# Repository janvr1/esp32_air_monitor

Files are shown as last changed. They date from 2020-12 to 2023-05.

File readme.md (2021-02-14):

### TO-DO:
* (SW) Ubidots

### Notes:
* GPIO 6-11: SPI flash
* GPIO 16-17: PSRAM
* GPIO 34-39: Input only
* EWMA filter: alpha = 2\*pi\*fc\*Ts/(1+2\*pi\*fc\*Ts)

### Display timings:
* F_pwm = 312,5 kHz (T=3,2 us)
* PWM: T_low@100%duty=~20 ns
* T_transfer = ~22 us (2 rows of 64 pixels * 3 colors)
* T_row = 200 us (T_transfer + 178 delay)
* Minimum brightness: T_on = 22 us (transfer time), T_off = 178 us (178 us delay)
* Maximum brightness: T_on = 200 us (22 us transfer + 178 us delay), T_off = 0 us
* Frame rate: 200..250 Hz (daylight), 100 Hz (nighttime)

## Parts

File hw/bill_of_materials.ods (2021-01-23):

Reference | Product | Type | Quantity | Price | Link
U1 | Microcontroller | Espressif DevKitC v4 | 1 | 10,00 € | Mouser (https://eu.mouser.com/ProductDetail/356-ESP32-DEVKITC32E/)
U2 | CO2 sensor | Sensirion SCD30 | 1 | 55,00 € | Mouser (https://eu.mouser.com/ProductDetail/403-SCD30/)
(J5) | T,RH sensor | Bosch BME280 | 1 | 15,00 € | Mouser (https://eu.mouser.com/ProductDetail/397-PIM472/)
(J4) | Light sensor | Vishay VEML7700 | 1 | 5,00 € | Mouser (https://eu.mouser.com/ProductDetail/485-4162/)
J2, J3 | Display connector | 2x8 Pin socket | 2
 | Display | 64x32 P3 Led matrix | 1 | 25,00 € | Ebay (https://www.ebay.com/itm/Panneau-de-pixels-LED-Matrix-P3-RVB-affichage-vidéo-HD-64x32-Module-décran-LED/273803679685)
J4 | Sensor connector | 1x5 Pin socket | 2
 | Sensor connector | 1x5 Pin header | 1
 | Sensor connector | 1x5 Pin header (right angle) | 1
J6 | Sensor connector | 1x7 Pin socket | 1
 | Sensor connector | 1x7 Pin header | 1
J1 | Power connector | 1x2 Pin header | 1
J1 | Power connector | 1x2 Pin socket | 1
 | Resistor | 10k SMD3216 | 7
 | DIP switch | x4 W7.62mm P2.54mm | 1
 | Button |  | 3

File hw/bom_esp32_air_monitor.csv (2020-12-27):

Id | Designator | Package | Quantity | Designation | Supplier and ref
1 | U1 | MODULE_ESP32-DEVKITC-32D | 1 | ESP32-DEVKITC-32D
2 | U2 | MODULE_SCD30 | 1 | SCD30
3 | J2,J3 | Connector_LED_matrix_64x32 | 2 | Connector_LED_matrix_64x32
4 | J5 | Connector_Adafruit_VEML7700 | 1 | Connector_Adafruit_VEML7700
5 | J4 | Connector_Pimoroni_BME280 | 1 | Connector_Pimoroni_BME280
6 | J1 | PinHeader_1x02_P2.54mm_Vertical | 1 | Conn_01x02_Male

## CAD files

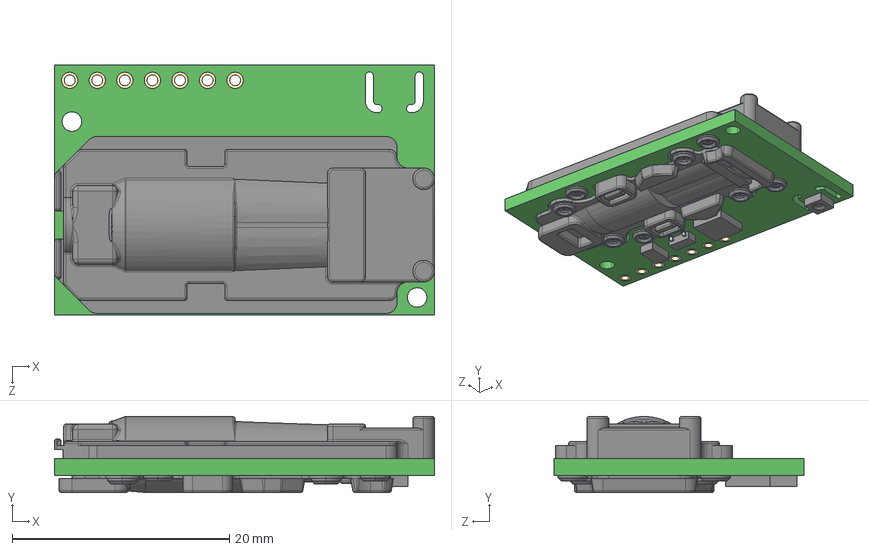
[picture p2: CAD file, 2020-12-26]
hw/libraries_footprints/kicad_SCD30/SCD30.step
35.0 x 7.00 x 23.0 mm

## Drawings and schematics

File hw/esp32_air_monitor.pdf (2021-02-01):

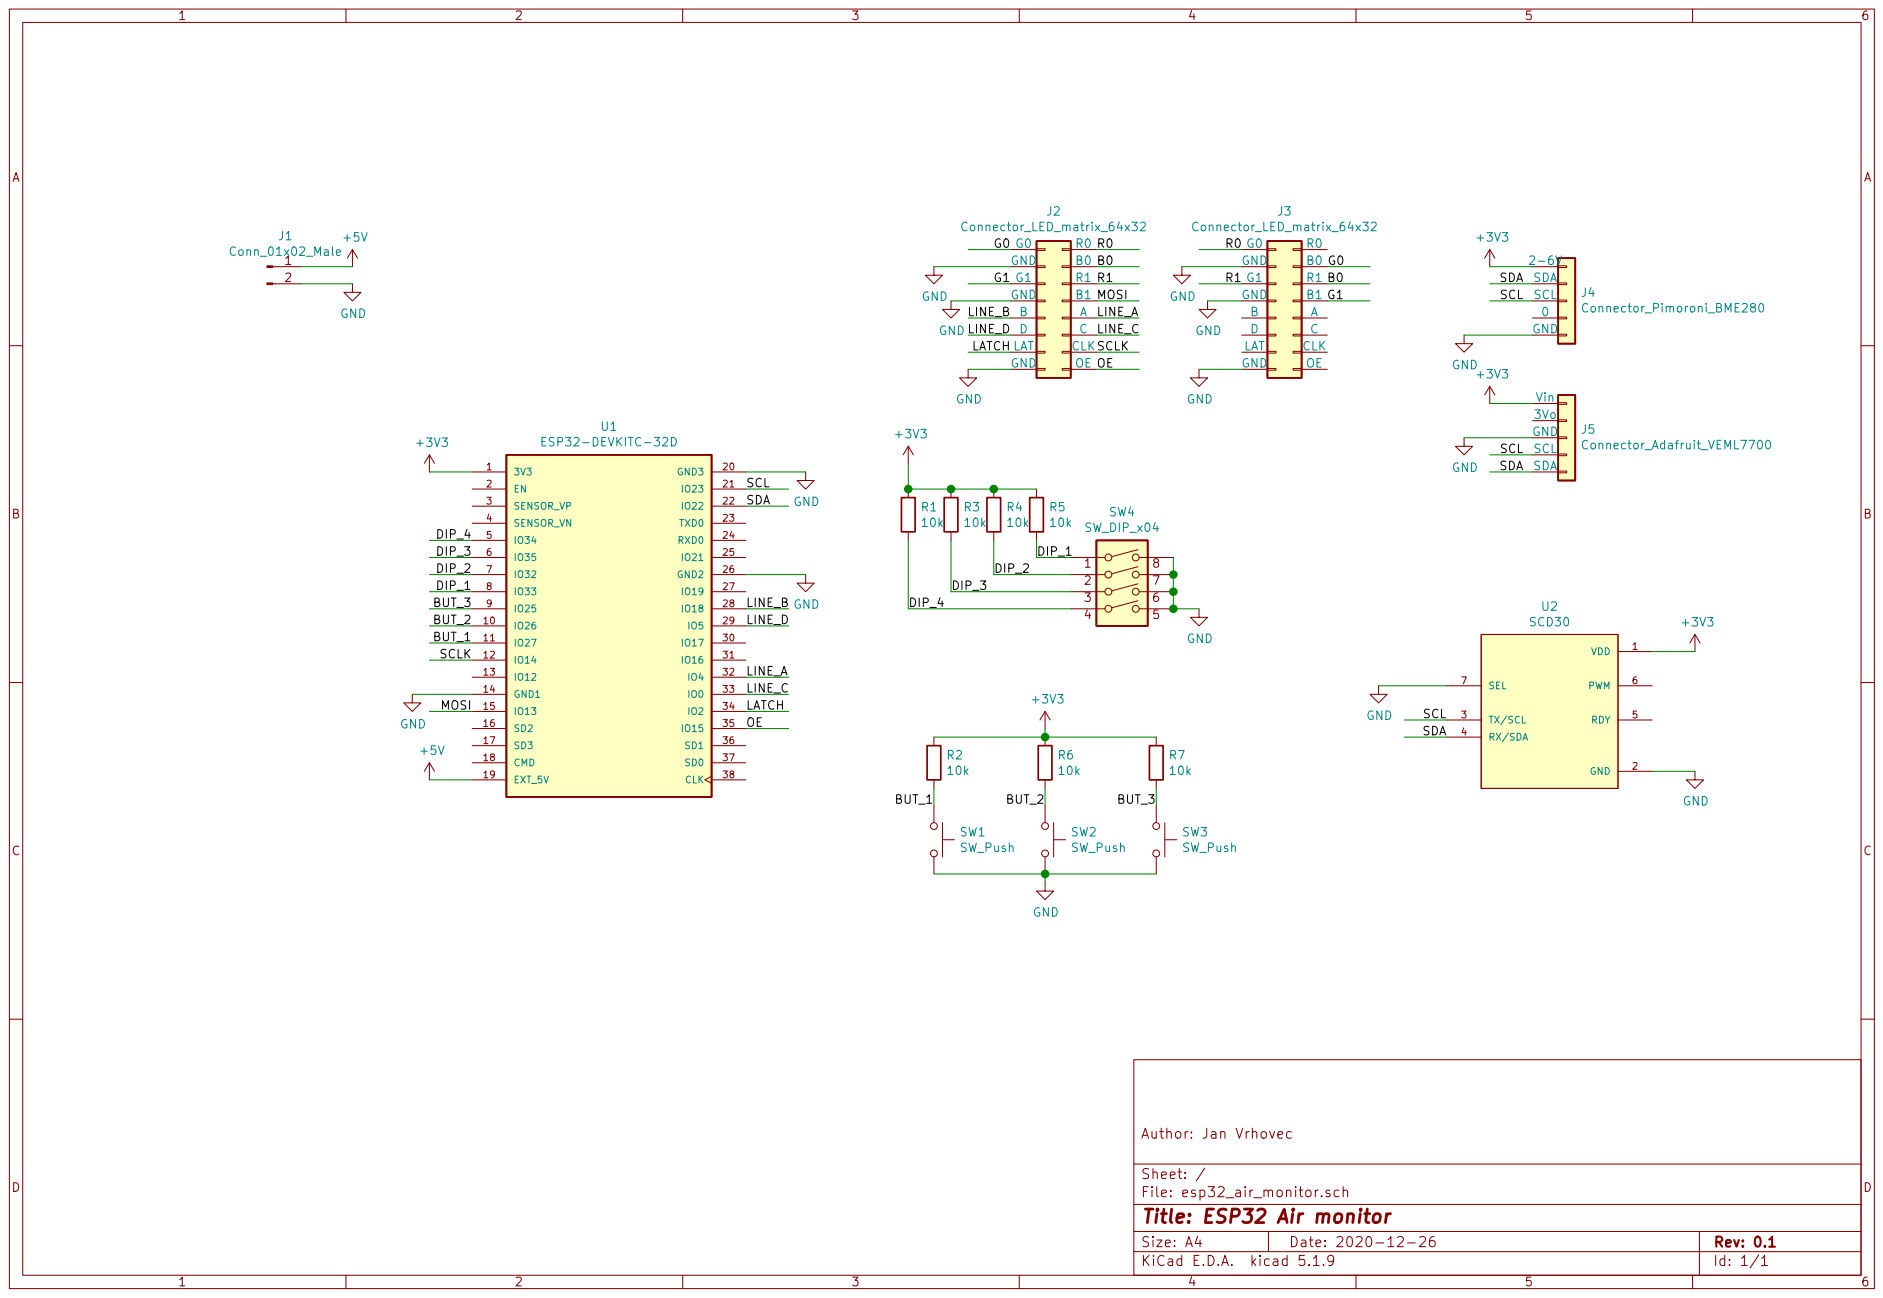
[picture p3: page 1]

File: esp32_air_monitor.sch Sheet: / Author: Jan Vrhovec

Id: 1/1 Title: ESP32 Air monitor

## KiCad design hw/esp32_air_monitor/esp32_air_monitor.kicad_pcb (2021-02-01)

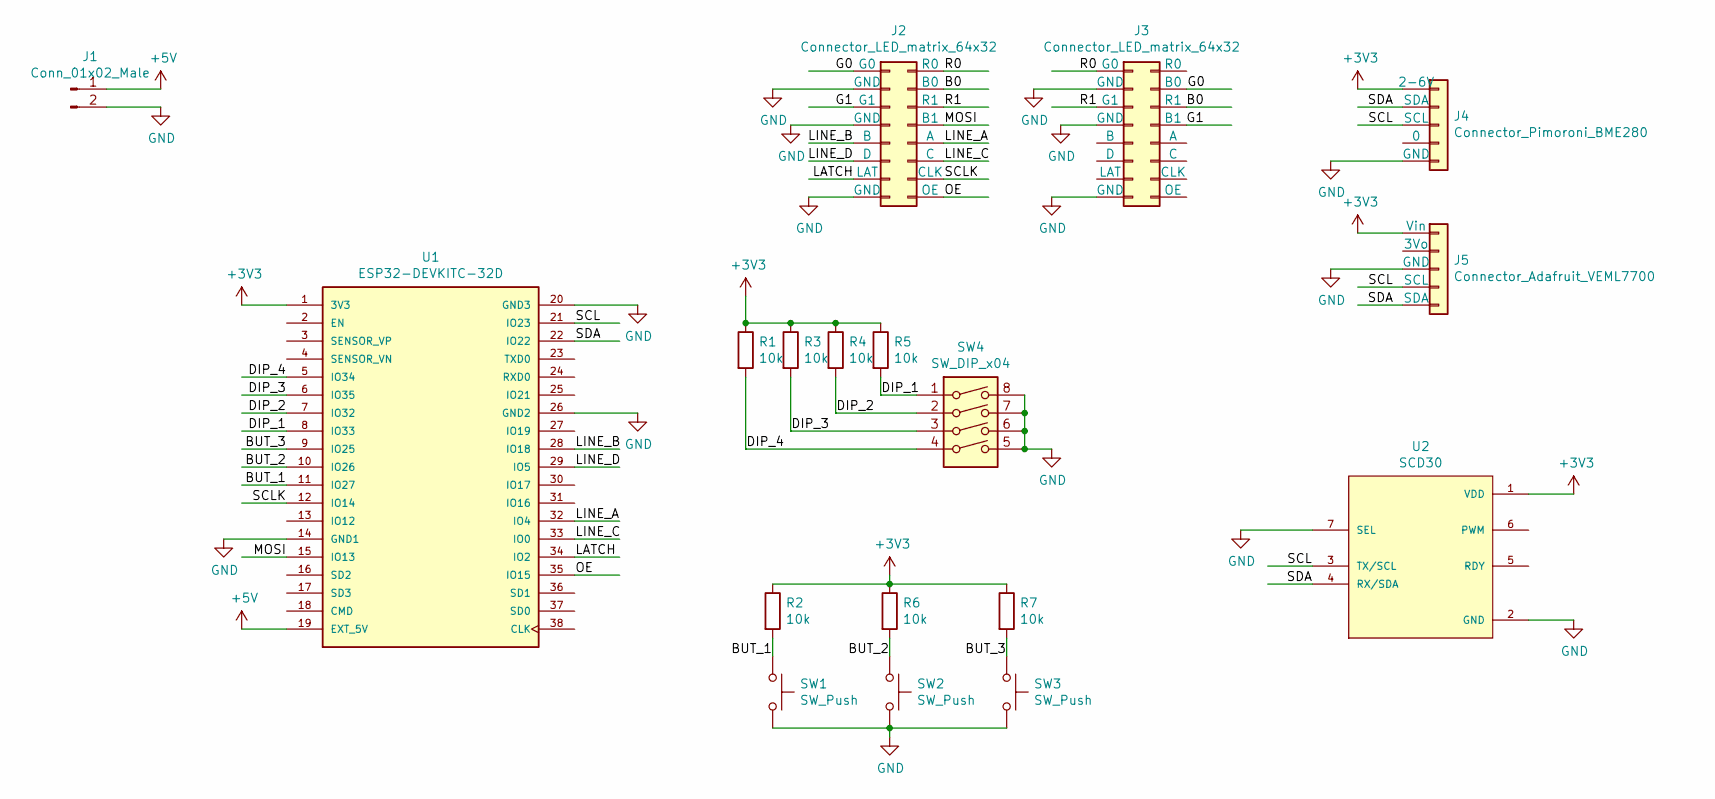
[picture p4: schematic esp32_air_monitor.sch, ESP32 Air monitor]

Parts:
J1: Conn_01x02_Male; PinHeader_1x02_P2.54mm_Vertical
J2, J3: Connector_LED_matrix_64x32
J4: Connector_Pimoroni_BME280
J5: Connector_Adafruit_VEML7700
R1, R2, R3, R4, R5, R6, R7: 10k; R_1206_3216Metric_Pad1.30x1.75mm_HandSolder
SW1, SW2, SW3: SW_Push; Push_Button_6x6mm
SW4: SW_DIP_x04; SW_DIP_SPSTx04_Slide_9.78x12.34mm_W7.62mm_P2.54mm
U1: ESP32-DEVKITC-32D; MODULE_ESP32-DEVKITC-32D; PARTREV 4
U2: SCD30; MODULE_SCD30; PARTREV D1

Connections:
+3V3: J4.1 (2-6V), J5.1 (Vin), R1.1, R2.1, R3.1, R4.1, R5.1, R6.1, R7.1, U1.1 (3V3), U2.1 (VDD)
+5V: J1.1, U1.19 (EXT_5V)
/B0: J2.4 (B0), J3.6 (R1)
/BUT_1: R2.2, SW1.1, U1.11 (IO27)
/BUT_2: R6.2, SW2.1, U1.10 (IO26)
/BUT_3: R7.2, SW3.1, U1.9 (IO25)
/DIP_1: R5.2, SW4.1, U1.8 (IO33)
/DIP_2: R4.2, SW4.2, U1.7 (IO32)
/DIP_3: R3.2, SW4.3, U1.6 (IO35)
/DIP_4: R1.2, SW4.4, U1.5 (IO34)
/G0: J2.1 (G0), J3.4 (B0)
/G1: J2.5 (G1), J3.8 (B1)
/LATCH: J2.13 (LAT), U1.34 (IO2)
/LINE_A: J2.10 (A), U1.32 (IO4)
/LINE_B: J2.9 (B), U1.28 (IO18)
/LINE_C: J2.12 (C), U1.33 (IO0)
/LINE_D: J2.11 (D), U1.29 (IO5)
/MOSI: J2.8 (B1), U1.15 (IO13)
/OE: J2.16 (OE), U1.35 (IO15)
/R0: J2.2 (R0), J3.1 (G0)
/R1: J2.6 (R1), J3.5 (G1)
/SCL: J4.3 (SCL), J5.4 (SCL), U1.21 (IO23), U2.3 (TX/SCL)
/SCLK: J2.14 (CLK), U1.12 (IO14)
/SDA: J4.2 (SDA), J5.5 (SDA), U1.22 (IO22), U2.4 (RX/SDA)
GND: J1.2, J2.3 (GND), J2.7 (GND), J2.15 (GND), J3.3 (GND), J3.7 (GND), J3.15 (GND), J4.5 (GND), J5.3 (GND), SW1.2, SW2.2, SW3.2, SW4.5, SW4.6, SW4.7, SW4.8, U1.14 (GND1), U1.20 (GND3), U1.26 (GND2), U2.2 (GND), U2.7 (SEL)

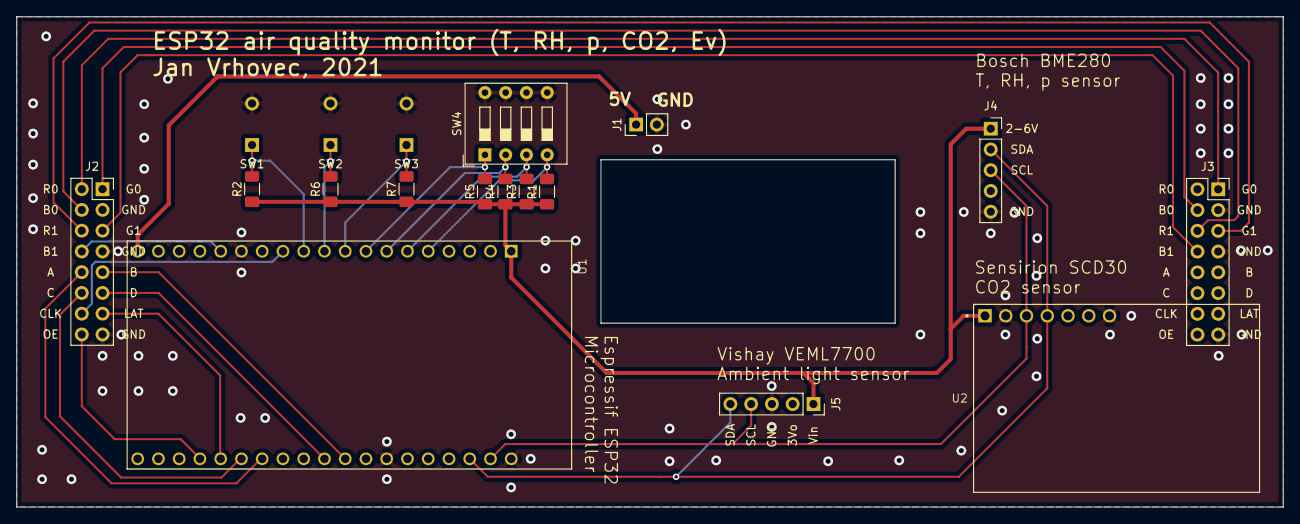
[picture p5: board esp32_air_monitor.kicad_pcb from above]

Board: 2 copper layers, 155.0 x 60.0 mm, 18 parts (0 on the bottom side), 25 nets.

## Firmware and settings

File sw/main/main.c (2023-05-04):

// #define LOG_LOCAL_LEVEL ESP_LOG_DEBUG

// System libraries
#include <stdio.h>
#include <math.h>

#include <lwip/apps/netbiosns.h>
#include <esp_log.h>
#include <esp_task.h>
#include <esp_sntp.h>
#include <esp_wifi.h>
#include <driver/i2c.h>

// Own libraries
#include <mdns.h>
#include <jan_bme280.h>
#include <jan_scd30.h>
#include <jan_veml7700.h>
#include <led_matrix.h>
#include <zrak_api.h>

#include "web_app/web_app.h"
#include "jan_nvs.h"
#include "jan_wifi.h"

// Logging tag
static const char *TAG = "MAIN";

// MDNS
#define APP_MDNS_INSTANCE_NAME "ESP32 air monitor"

// I2C parameters
#define I2C_GPIO_SDA 22
#define I2C_GPIO_SCL 23
#define I2C_FREQUENCY 50000

// IIR filter parameters (SCD30)
#define CO2_INTERVAL 3.0
#define T_CUTOFF 30.0

// LED matrix pins
#define OE 15
#define LATCH 2
#define LINE_A 4
#define LINE_B 18
#define LINE_C 0
#define LINE_D 5

#define GUI_STR_TIME "%02" PRIu16 ":%02" PRIu16 ":%02" PRIu16 ""
#define GUI_STR_DATE "%02" PRIu16 ".%02" PRIu16 ".%02" PRIu16 ""
#define GUI_STR_T_RH "%02" PRIu16 "`C %02" PRIu16 "%%"
#define GUI_STR_CO2 "%*" PRIu16 " ppm"
#define GUI_STR_BLANK "        "

// Led matrix handle
led_matrix_t lm;

// Function declarations
static void initialize_mdns(char *hostname);
static void initialize_sntp(void);
static void wifi_event_handler_main(void *arg, esp_event_base_t event_base, int32_t event_id, void *event_data);
float calculate_duty(float lux);

// Task functions
static void display(void *pvParameters);
static void startup_animation(void *pvParameters);

void app_main(void)
{
    printf("Hello world!\n");
    esp_err_t ret;

    // esp_log_level_set(TAG, ESP_LOG_WARN);

    // I2C configuration
    i2c_config_t i2c_conf = {
        .mode = I2C_MODE_MASTER,
        .sda_io_num = I2C_GPIO_SDA,
        .scl_io_num = I2C_GPIO_SCL,
        .sda_pullup_en = GPIO_PULLUP_ENABLE,
        .scl_pullup_en = GPIO_PULLUP_ENABLE,
        .master.clk_speed = I2C_FREQUENCY,
    };
    i2c_param_config(I2C_NUM_0, &i2c_conf);
    i2c_driver_install(I2C_NUM_0, I2C_MODE_MASTER, 0, 0, 0);

    // BME280 configuration
    bme280_dev_t bme280;
    bme280_params_t bme280_params;
    bme280_default_params(&bme280_params);
    bme280_params.iir_filter = BME280_FILTER_X8;
    bme280_params.mode = BME280_MODE_FORCED;
    bme280_params.standby_time = BME280_STANDBY_MS_1000;
    ret = bme280_begin(&bme280, &bme280_params, BME280_I2C_ADDRESS, I2C_NUM_0);
    ESP_ERROR_CHECK_WITHOUT_ABORT(ret);
    if (ret != ESP_OK)
        ESP_LOGE(TAG, "Error initializing BME280");

    // SCD30 configuration
    scd30_dev_t scd30;
    ret = scd30_begin(&scd30, I2C_NUM_0, CO2_INTERVAL, T_CUTOFF);
    ESP_ERROR_CHECK_WITHOUT_ABORT(ret);
    if (ret != ESP_OK)
        ESP_LOGE(TAG, "Error initializing SCD30");
    // ESP_ERROR_CHECK_WITHOUT_ABORT(scd30_set_altitude_comp(&scd30, 300));
    vTaskDelay(10 / portTICK_PERIOD_MS);
    ESP_ERROR_CHECK_WITHOUT_ABORT(scd30_set_temp_offset(&scd30, 0));
    vTaskDelay(100 / portTICK_PERIOD_MS);
    ESP_ERROR_CHECK_WITHOUT_ABORT(scd30_start_measurement(&scd30, 0));
    bool scd30_comp = false;

    // VEML7700 configuration
    veml7700_dev_t veml;
    veml7700_begin(&veml, I2C_NUM_0, true);

    // Timezone confiugration
    setenv("TZ", "CET-1CEST-2,M3.5.0/02:00:00,M10.5.0/03:00:00", 1);
    tzset();

    // LED matrix configuration
    ret = lm_init(&lm, LINE_A, LINE_B, LINE_C, LINE_D, OE, LATCH);
    ESP_ERROR_CHECK_WITHOUT_ABORT(ret);

    lm_draw_text(&lm, "Hello", 0, 1, LM_COLOR_GREEN);
    lm_draw_text(&lm, "world!", 2, 2, LM_COLOR_GREEN);

    // Create the task that refreshes the display
    TaskHandle_t display_task;
    xTaskCreatePinnedToCore(display, "task_display", 4096, NULL, 10, &display_task, 1);

    // Create the task that draws the startup animation
    TaskHandle_t startup_task;
    xTaskCreate(startup_animation, "task_startup_animation", 1024, NULL, 0, &startup_task);

    // Initialize NVS
    nvs_init();

    // WiFi configuration
    esp_event_loop_create_default(); // Eevent loop for wifi
    esp_netif_t *netif;
    char ssid[32];
    char pass[64];
    bool connected = false;
    ret = nvs_get_wifi_ssid_pass(ssid, pass);
    ESP_ERROR_CHECK_WITHOUT_ABORT(ret);
    if (strlen(ssid) == 0 || strlen(pass) == 0)
    {
        ESP_LOGE(TAG, "Wifi SSID/pass is 0 length! Using AP mode...");
        ret = ESP_FAIL;
    }
    if (ret == ESP_OK)
    {
        netif = wifi_init_sta(ssid, pass, &connected);
        if (!connected)
        {
            jan_wifi_deinit();
            netif = wifi_init_softap();
        }
    }
    else
    {
        netif = wifi_init_softap();
    }

    wifi_mode_t wifimode;
    ret = esp_wifi_get_mode(&wifimode);
    ESP_ERROR_CHECK_WITHOUT_ABORT(ret);

    // Stop the startup animation
    vTaskDelete(startup_task);

    // Clear the frame
    lm_clear_frame(&lm);

    // Display the network information on screen
    if (wifimode == WIFI_MODE_STA)
    {
        esp_netif_ip_info_t ip_info;
        esp_netif_get_ip_info(netif, &ip_info);
        uint32_t ipaddr = ntohl(ip_info.ip.addr);
        uint8_t A = ipaddr >> 24;
        uint8_t B = (ipaddr >> 16) & 0xFF;
        uint8_t C = (ipaddr >> 8) & 0xFF;
        uint8_t D = ipaddr & 0xFF;
        char line1[9];
        char line2[9];
        sprintf(line1, "%*d.%" PRIu8 ".", 3, A, B);
        sprintf(line2, "%*d.%" PRIu8 "", 3, C, D);

        lm_draw_text(&lm, "IP ADDR:", 0, 0, LM_COLOR_RED);
        lm_draw_text(&lm, line1, 0, 2, LM_COLOR_RED);
        lm_draw_text(&lm, line2, 1, 3, LM_COLOR_RED);
    }
    else if (wifimode == WIFI_MODE_AP)
    {
        lm_draw_text(&lm, "AP", 3, 0, LM_COLOR_RED);
        lm_draw_text(&lm, "MODE", 2, 1, LM_COLOR_RED);
        lm_draw_text(&lm, "passwd:", 0, 2, LM_COLOR_RED);
        lm_draw_text(&lm, WIFI_AP_PASS, 0, 3, LM_COLOR_RED);
    }
    else
    {
        ESP_LOGW(TAG, "Unexpected wifi mode");
    }

    // If we are connected to wifi, update time from SNTP and start wifi event handler
    if (wifimode == WIFI_MODE_STA)
    {
        initialize_sntp();
        ret = esp_event_handler_register(WIFI_EVENT, ESP_EVENT_ANY_ID, &wifi_event_handler_main, NULL);
        ESP_ERROR_CHECK_WITHOUT_ABORT(ret);
    }

    // mDNS configuration
    char hostname[64];
    nvs_get_device_name(hostname);
    if (strlen(hostname) == 0)
    {
        ESP_LOGW(TAG, "Hostname 0 length! using \"esp32\"");
        initialize_mdns("esp32");
    }
    else
    {
        ESP_LOGI(TAG, "Initializing mdns with hostname: %s", hostname);
        initialize_mdns(hostname);
    }

    // Zrak API configuration
    bool zrak_api = false;
    bool zrak_api_sent = false;
    char zrak_user[64] = {};
    char zrak_pass[64] = {};
    uint32_t zrak_dev_id = 0;
    ret = nvs_get_zrak_api_credentials(zrak_user, zrak_pass, &zrak_dev_id);
    ESP_ERROR_CHECK_WITHOUT_ABORT(ret);
    if (strlen(zrak_user) > 0 && strlen(zrak_pass) > 0 && zrak_dev_id != 0)
    {
        zrak_api = true;
        ESP_LOGI(TAG, "Zrak API activated");
    }
    else
    {
        ESP_LOGW(TAG, "Zraki API not activated");
    }
    ESP_LOGI(TAG, "Zrak API user: %s", zrak_user);
    ESP_LOGI(TAG, "Zrak API pass: %s", zrak_pass);
    ESP_LOGI(TAG, "Zrak API dev_id: %" PRIu32 "", zrak_dev_id);

    // Web app configuration
    // httpd_handle_t server = NULL;
    ret = web_app_init(netif, &bme280, &scd30, &veml);
    if (ret == ESP_OK)
    {
        ESP_LOGI(TAG, "Successfully started HTTP server");
    }

    uint32_t count = 0;
    int8_t data_ready = 0;

    float duty = 64; // Starting value for duty cyle IIR filter

    // Variables to display on screen
    int co2 = 0, t = 0, rh = 0;
    lm_color_t co2_color = LM_COLOR_GREEN;
    lm_color_t t_rh_color = LM_COLOR_BLUE;

    char text_time[9] = {};
    char text_date[9] = {};
    char text_t_rh[9] = {};
    char text_co2[9] = {};

    // Time keeping
    time_t now;
    struct tm timeinfo;
    time(&now);
    localtime_r(&now, &timeinfo);

    // Delay so the netowrk info stays on screen for longer
    vTaskDelay(4000 / portTICK_PERIOD_MS);
    lm_clear_frame(&lm);

    // Loop
    while (1)
    {
        // Read ambient light data and set duty cycle accordingly
        ESP_ERROR_CHECK_WITHOUT_ABORT(veml7700_read_als(&veml));
        duty = 0.3 * calculate_duty(veml.als) + 0.7 * duty;
        lm_set_duty(&lm, round(duty));
        ESP_LOGI(TAG, "Duty: %f, %" PRIu16 "", round(duty), lm.duty);

        // If ambient light is low, change T and RH display to red color
        if (duty < 15)
        {
            t_rh_color = LM_COLOR_RED;
            lm_draw_text(&lm, GUI_STR_BLANK, 0, 2, LM_COLOR_BLUE);
            sprintf(text_t_rh, GUI_STR_T_RH, t, rh);
            lm_draw_text(&lm, text_t_rh, 0, 2, t_rh_color);
        }
        else
        {
            t_rh_color = LM_COLOR_BLUE;
            lm_draw_text(&lm, GUI_STR_BLANK, 0, 2, LM_COLOR_RED);
            sprintf(text_t_rh, GUI_STR_T_RH, t, rh);
            lm_draw_text(&lm, text_t_rh, 0, 2, t_rh_color);
        }

        // Read current time
        time(&now);
        localtime_r(&now, &timeinfo);

        // Update time on screen
        strftime(text_time, 9, "%H:%M:%S", &timeinfo);
        lm_draw_text(&lm, text_time, 0, 0, LM_COLOR_RED);
        strftime(text_date, 9, "%d.%m.%y", &timeinfo);
        lm_draw_text(&lm, text_date, 0, 1, LM_COLOR_RED);

        ESP_LOGI(TAG, "Count: %" PRIu32 "", count / 5);

        // Every 5 seconds, read the sensor data
        if (count % 5 == 0)
        {
            ESP_LOGI(TAG, "Measurement count: %" PRIu32 "", count / 5);

            // Read BME280
            ESP_ERROR_CHECK_WITHOUT_ABORT(bme280_measurement(&bme280));
            t = (int)round(bme280.temperature);
            rh = (int)round(bme280.humidity);

            // Wait for SCD30 data ready
            do
            {
                data_ready = scd30_data_ready(&scd30);
                if (data_ready < 0)
                    ESP_LOGI(TAG, "SCD30 data_ready -1");
                else if (data_ready < 1)
                    ESP_LOGI(TAG, "Waiting for SCD30 data to be ready");
                vTaskDelay(100 / portTICK_PERIOD_MS);
            } while (data_ready != 1);

            // Read SCD30 data
            ESP_ERROR_CHECK_WITHOUT_ABORT(scd30_read_measurement(&scd30));
            co2 = (int)round(scd30.co2);

            // If CO2 value is over 1499 ppm (or ambient light is very low), change its display color to red
            if (co2 > 1499 || duty < 3.5)
            {
                co2_color = LM_COLOR_RED;
                lm_draw_text(&lm, GUI_STR_BLANK, 0, 3, LM_COLOR_GREEN);
            }
            else
            {
                co2_color = LM_COLOR_GREEN;
                lm_draw_text(&lm, GUI_STR_BLANK, 0, 3, LM_COLOR_RED);
            }

            // Draw the sensor data on screen
            sprintf(text_t_rh, GUI_STR_T_RH, t, rh);
            lm_draw_text(&lm, text_t_rh, 0, 2, t_rh_color);
            sprintf(text_co2, GUI_STR_CO2, 4, co2);
            lm_draw_text(&lm, text_co2, 0, 3, co2_color);

            // Every full hour, update compensation data on SCD30
            if ((timeinfo.tm_min == 0) && !scd30_comp)
            {
                float offset = scd30.temperature - bme280.temperature;
                if (offset > 0)
                    scd30_set_temp_offset(&scd30, offset); // Temperature compensation
                vTaskDelay(100 / portTICK_PERIOD_MS);
                scd30_start_measurement(&scd30, round(bme280.pressure) / 100); // Pressure compensation
                vTaskDelay(200 / portTICK_PERIOD_MS);
                scd30_comp = true;
            }
            else if ((timeinfo.tm_min > 0) && scd30_comp)
            {
                scd30_comp = false;
            }

            // Every half an hour, send Zrak API data to cloud, if enabled
            if (zrak_api && !zrak_api_sent && (timeinfo.tm_min == 30 || timeinfo.tm_min == 0))
            {
                zrak_send_measurements(zrak_user, zrak_pass, zrak_dev_id,
                                       bme280.temperature,
                                       bme280.humidity,
                                       bme280.pressure,
                                       scd30.co2,
                                       veml.als);
                zrak_api_sent = true;
            }
            else if (zrak_api && zrak_api_sent && (timeinfo.tm_min == 31 || timeinfo.tm_min == 1))
                zrak_api_sent = false;
        }
        count++;
        vTaskDelay(1000 / portTICK_PERIOD_MS);
    }
}

static void wifi_event_handler_main(void *arg, esp_event_base_t event_base,
                                    int32_t event_id, void *event_data)
{
    if (event_id == WIFI_EVENT_STA_DISCONNECTED)
    {
        ESP_LOGW(TAG, "Lost wifi connection. Retrying in 30 seconds");
        vTaskDelay(30000 / portTICK_PERIOD_MS);
        ESP_LOGI(TAG, "Retrying WiFi connection...");
        esp_err_t ret = esp_wifi_connect();
        ESP_ERROR_CHECK_WITHOUT_ABORT(ret);
    }
}

static void initialize_mdns(char *hostname)
{
    mdns_init();
    mdns_hostname_set(hostname);
    mdns_instance_name_set(APP_MDNS_INSTANCE_NAME);

    netbiosns_init();
    netbiosns_set_name(hostname);
}

static void initialize_sntp(void)
{
    ESP_LOGI(TAG, "Initializing SNTP");
    sntp_setoperatingmode(SNTP_OPMODE_POLL);
    sntp_setservername(0, "pool.ntp.org");
    sntp_init();
}

static void display(void *pvParameters)
{
    while (1)
    {
        lm_show_frame(&lm);
        vTaskDelay(1);
        if (lm.duty == 255)
        {
            vTaskDelay(5 / portTICK_PERIOD_MS);
        }
    }
}
static void startup_animation(void *pvParameters)
{
    while (1)
    {
        for (int i = 0; i < 32; i++)
        {
            for (int j = 0; j < 64; j++)
            {
                lm_set_pixel(&lm, 1, j, i, LM_COLOR_RED);
                vTaskDelay(20 / portTICK_PERIOD_MS);
            }
        }
        lm_clear_frame(&lm);
    }
}

float calculate_duty(float lux)
{
    if (lux < 10)
        return lux * 2;
    else if (lux < 30)
        return 20 + lux;
    else if (lux < 100)
        return 50 + lux / 2;
    else if (lux < 620)
        return 100 + lux / 4;
    else
        return 255;
}

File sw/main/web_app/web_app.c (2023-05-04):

// #define LOG_LOCAL_LEVEL ESP_LOG_DEBUG

#include "web_app.h"
#include <string.h>
#include <fcntl.h>
#include <cJSON.h>
#include <math.h>
#include <esp_log.h>
#include <esp_wifi.h>
#include <esp_spiffs.h>
#include <esp_http_server.h>
#include <esp_heap_caps.h>
#include "lwip/sys.h"
#include "../utilities/jan_nvs.h"


#define CHECK_FILE_EXTENSION(filename, ext) (strcasecmp(&filename[strlen(filename) - strlen(ext)], ext) == 0)

static const char *TAG = "JAN_WEB_APP";

// static web_app_context_t web_ctx;

esp_err_t spiffs_init();
static esp_err_t get_file_handler(httpd_req_t *req);
static esp_err_t get_measurement_handler(httpd_req_t *req);
static esp_err_t get_info_handler(httpd_req_t *req);
static esp_err_t post_dev_info_handler(httpd_req_t *req);
static esp_err_t post_wifi_handler(httpd_req_t *req);
static esp_err_t post_scd_asc_handler(httpd_req_t *req);
static esp_err_t post_scd_frc_handler(httpd_req_t *req);
static esp_err_t post_zrak_handler(httpd_req_t *req);
static esp_err_t read_req_data(httpd_req_t *req, char *buf, size_t maxlen);
static esp_err_t set_content_type_from_file(httpd_req_t *req, const char *filepath);

esp_err_t web_app_init(esp_netif_t *netif,
                       bme280_dev_t *bme,
                       scd30_dev_t *scd,
                       veml7700_dev_t *veml)
{
    // Return value
    esp_err_t ret;

    // Intialize flash storage
    ret = spiffs_init();
    if (ret != ESP_OK)
        return ret;

    httpd_handle_t server = NULL;

    // Intialize HTTP server
    httpd_config_t conf_httpd = HTTPD_DEFAULT_CONFIG();
    conf_httpd.uri_match_fn = httpd_uri_match_wildcard;
    conf_httpd.core_id = 0;
    conf_httpd.task_priority = 5;

    ESP_LOGI(TAG, "Starting HTTP Server");
    ret = httpd_start(&server, &conf_httpd);
    ESP_ERROR_CHECK_WITHOUT_ABORT(ret);
    if (ret != ESP_OK)
    {
        return ret;
    }

    // Register URI handlers
    web_app_context_t *web_ctx = calloc(1, sizeof(web_app_context_t));
    if (web_ctx == NULL)
    {
        ESP_LOGE(TAG, "Failed to allocate memory for web_app_context");
        return ESP_FAIL;
    }

    web_ctx->scd = scd;
    web_ctx->bme = bme;
    web_ctx->veml = veml;
    web_ctx->netif = netif;
    web_ctx->buffer = malloc(CHUNK_BUFSIZE);

    httpd_uri_t get_measurements_uri = {
        .uri = "/api/measurements",
        .method = HTTP_GET,
        .handler = get_measurement_handler,
        .user_ctx = web_ctx};
    httpd_register_uri_handler(server, &get_measurements_uri);

    httpd_uri_t get_info_uri = {
        .uri = "/api/info",
        .method = HTTP_GET,
        .handler = get_info_handler,
        .user_ctx = web_ctx};
    httpd_register_uri_handler(server, &get_info_uri);

    httpd_uri_t post_info_uri = {
        .uri = "/api/dev_info",
        .method = HTTP_POST,
        .handler = post_dev_info_handler,
        .user_ctx = NULL};
    httpd_register_uri_handler(server, &post_info_uri);

    httpd_uri_t post_wifi_uri = {
        .uri = "/api/wifi",
        .method = HTTP_POST,
        .handler = post_wifi_handler,
        .user_ctx = NULL};
    httpd_register_uri_handler(server, &post_wifi_uri);

    httpd_uri_t post_scd_asc_uri = {
        .uri = "/api/scd_asc",
        .method = HTTP_POST,
        .handler = post_scd_asc_handler,
        .user_ctx = web_ctx};
    httpd_register_uri_handler(server, &post_scd_asc_uri);

    httpd_uri_t post_scd_frc_uri = {
        .uri = "/api/scd_frc",
        .method = HTTP_POST,
        .handler = post_scd_frc_handler,
        .user_ctx = web_ctx};
    httpd_register_uri_handler(server, &post_scd_frc_uri);

    httpd_uri_t post_zrak_uri = {
        .uri = "/api/zrak",
        .method = HTTP_POST,
        .handler = post_zrak_handler,
        .user_ctx = NULL};
    httpd_register_uri_handler(server, &post_zrak_uri);

    httpd_uri_t get_file_uri = {.uri = "/*", .method = HTTP_GET, .handler = get_file_handler, .user_ctx = web_ctx};
    httpd_register_uri_handler(server, &get_file_uri);

    return ESP_OK;
}

void web_app_stop(httpd_handle_t *server)
{
    esp_vfs_spiffs_unregister(NULL);
    ESP_LOGI(TAG, "SPIFFS unmounted");
    httpd_stop(server);
}

static esp_err_t post_zrak_handler(httpd_req_t *req)
{
    esp_err_t ret;

    size_t maxlen = 256;
    char *buf = malloc(maxlen);
    ret = read_req_data(req, buf, maxlen);

    if (ret == ESP_ERR_INVALID_SIZE)
    {
        ESP_LOGE(TAG, "Received request data is larger than provided buffer");
        free(buf);
        httpd_resp_send_err(req, HTTPD_500_INTERNAL_SERVER_ERROR, "Content too long");
        return ESP_FAIL;
    }
    if (ret == ESP_FAIL)
    {
        ESP_LOGE(TAG, "Failed to read the request data");
        free(buf);
        httpd_resp_send_err(req, HTTPD_500_INTERNAL_SERVER_ERROR, "Failed to read request data");
        return ESP_FAIL;
    }

    cJSON *json = cJSON_Parse(buf);

    if (cJSON_HasObjectItem(json, "user") && cJSON_HasObjectItem(json, "pass") && cJSON_HasObjectItem(json, "dev_id"))
    {
        if (strlen(cJSON_GetObjectItem(json, "user")->valuestring) > 63)
        {
            ESP_LOGE(TAG, "Error: Zrak API username too long");
            httpd_resp_send_err(req, HTTPD_400_BAD_REQUEST, "Error: Username too long");
            cJSON_Delete(json);
            free(buf);
            return ESP_FAIL;
        }

        if (strlen(cJSON_GetObjectItem(json, "pass")->valuestring) > 63)
        {
            ESP_LOGE(TAG, "Error: Zrak API password too long");
            httpd_resp_send_err(req, HTTPD_400_BAD_REQUEST, "Error: Password too long");
            cJSON_Delete(json);
            free(buf);
            return ESP_FAIL;
        }

        ESP_LOGI(TAG, "Updating zrak API user & pass");

        ret = nvs_set_zrak_api_credentials(cJSON_GetObjectItem(json, "user")->valuestring,
                                           cJSON_GetObjectItem(json, "pass")->valuestring,
                                           cJSON_GetObjectItem(json, "dev_id")->valueint);
        ESP_ERROR_CHECK_WITHOUT_ABORT(ret);
        ESP_LOGD(TAG, "Zrak API user: %s", cJSON_GetObjectItem(json, "user")->valuestring);
        ESP_LOGD(TAG, "Zrak API pass: %s", cJSON_GetObjectItem(json, "pass")->valuestring);
        ESP_LOGD(TAG, "Zrak API dev_id: %"PRIi16"", cJSON_GetObjectItem(json, "dev_id")->valueint);

        if (ret == ESP_OK)
        {
            httpd_resp_sendstr(req, "Success: Updated Zrak API credentials successfully.\n");
        }
        else
        {
            httpd_resp_set_status(req, HTTPD_500);
            httpd_resp_sendstr(req, "Error: Failed to update Zrak API credentials.\n");
            cJSON_Delete(json);
            free(buf);
            return ESP_FAIL;
        }
    }
    else
    {
        ESP_LOGE(TAG, "Zrak API json missing fields");
        httpd_resp_send_err(req, HTTPD_400_BAD_REQUEST, "Error: Missing one of the required fields");
        cJSON_Delete(json);
        free(buf);
        return ESP_FAIL;
    }
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

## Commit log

2020-12-26 Initial commit. +Hardware files
    [SCD30.step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]
2021-01-09 Added VEML7700 driver, improved SCD30 and BME280 drivers
2021-01-10 Added webserver, other improvements
    [partitions.csv]
2021-01-12 Big improvements, huge! The best commit in the history of commits, maybe ever.
    [partitions.csv]
2021-01-13 Dodan led matrix display Dodana sinhronizacija časa prek sntpm, Dodan prikaz IP-ja ob prižigu
2021-01-16 Remove DMA for SPI transactions
    [bill_of_materials.ods]
2021-01-17 Update ledmatrix driver
2021-01-23 Update PCB
    [bill_of_materials.ods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]
2021-02-01 Fix hardware bug (SCL pin), patch software for new hw revision
    [esp32_air_monitor.kicad_pcb, esp32_air_monitor.sch]
2021-02-14 Try to reconnect every 30 seconds in case of lost wifi connetction
2023-05-04 Bugfix for wifi in AP mode Update to ESP-IDF v5
    [main.c, web_app.c]
